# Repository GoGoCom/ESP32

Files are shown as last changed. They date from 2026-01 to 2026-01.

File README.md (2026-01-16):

# ESP32

## Introduction

I created a heater temperature control system using Blynk and an ESP32. The ESP32 is a powerful device with WiFi and Bluetooth capabilities. By combining these two, I created an IoT system that allows remote heaters to be turned on and off at specific temperatures and time periods.
This sketch is implemented provisioning using BLE as the mode of transport for provisioning-related communication between the device (to be provisioned) and the client (owner of the device).

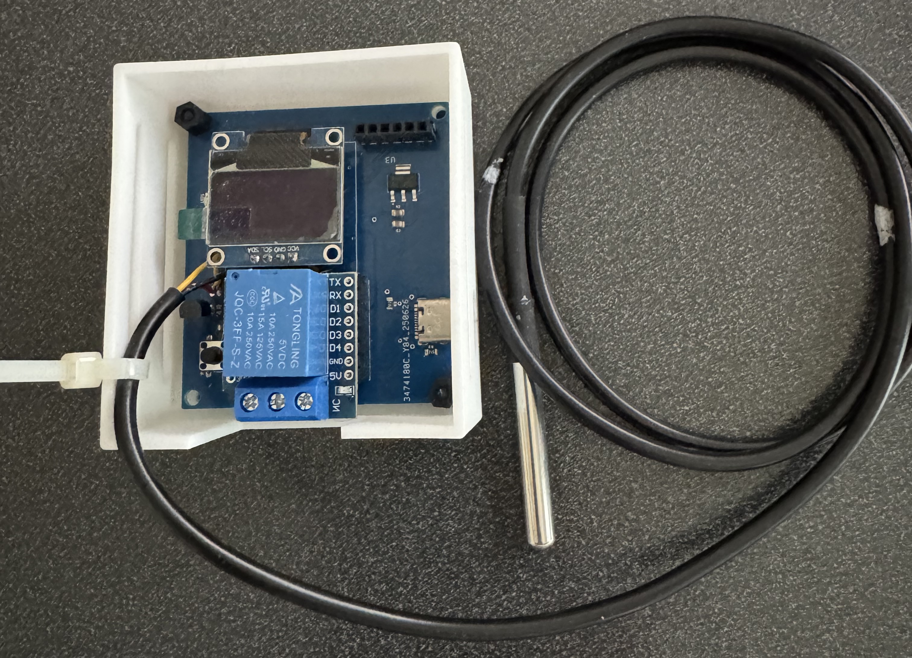
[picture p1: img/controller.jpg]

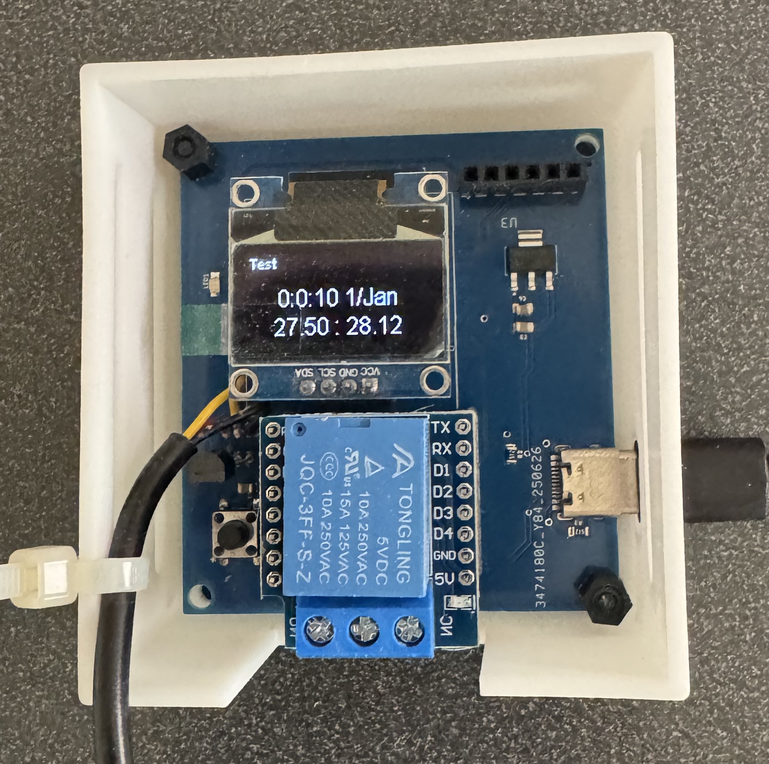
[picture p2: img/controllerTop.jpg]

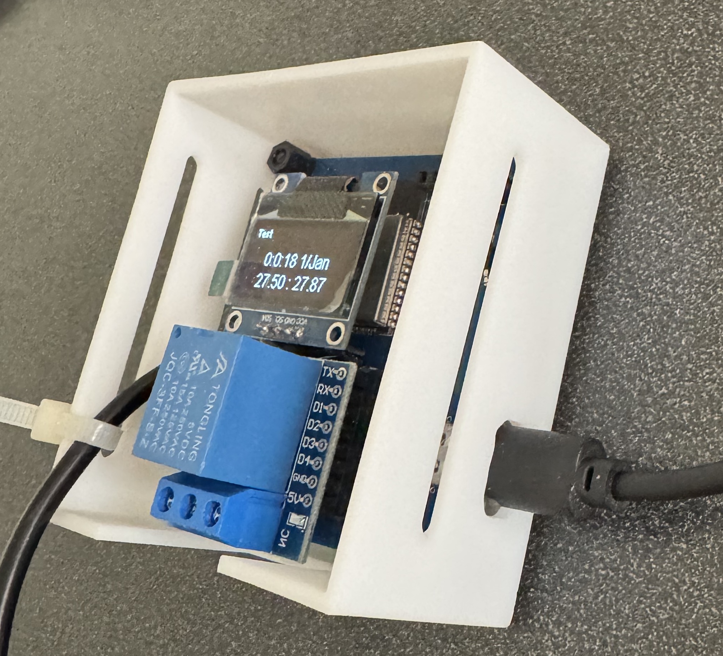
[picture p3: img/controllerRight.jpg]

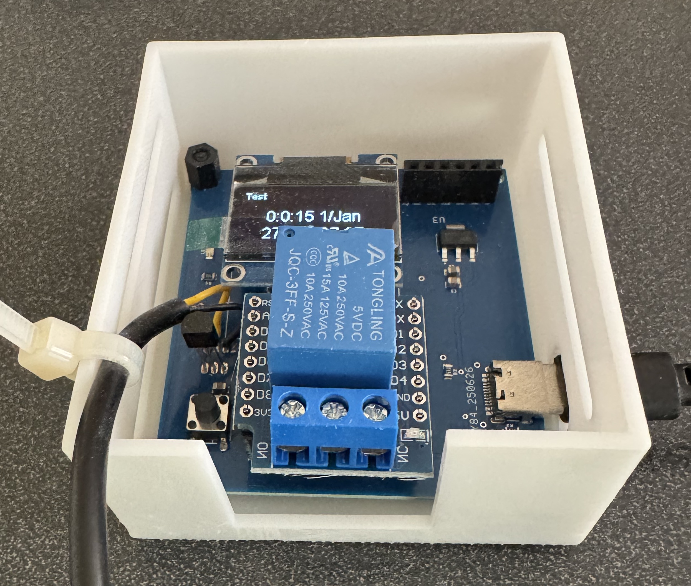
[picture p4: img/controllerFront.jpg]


## Provisioning Tools

### Provisioning using BLE
```

Provisioning started
Give Credentials of your access point using  of "Android app" or "apple asp" ESP BLE Prov.

Received Wi-Fi credentials
    SSID: your own ssid
    Password: your own password

Connected IP address: 192.168.43.120
Provisioning Successful
Provisioning Ends
```

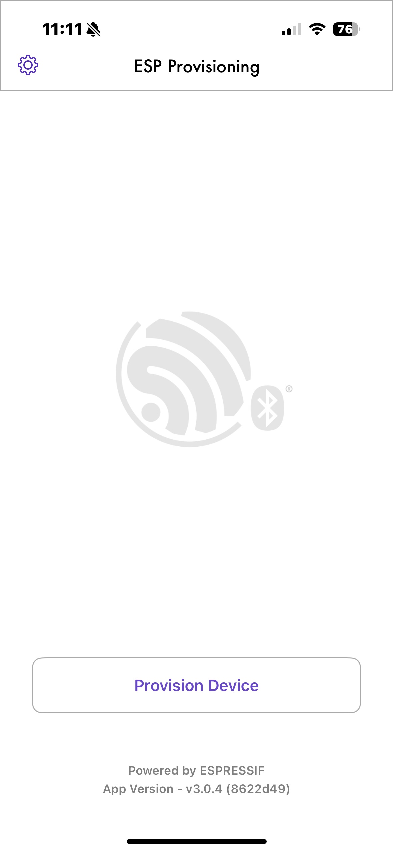
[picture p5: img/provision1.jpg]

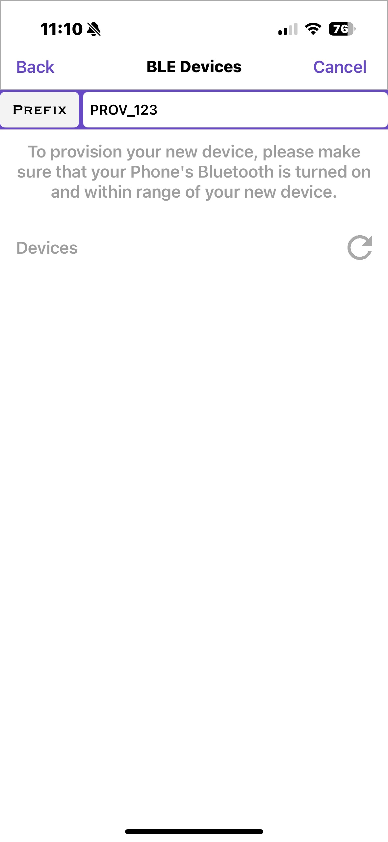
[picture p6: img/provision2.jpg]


## Blynk Tools

[Blynk](https://www.blynk.io/) is an excellent platform for solving IoT problems.It is the most powerful tool when you want to control something on the Internet, whether it is on mobile or PC.
By defining the required streams in the Blynk.Console and connecting them to components, you can exchange data over the network.
You must first sign up on https://blynk.cloud/dashboard/login  before you can use it.

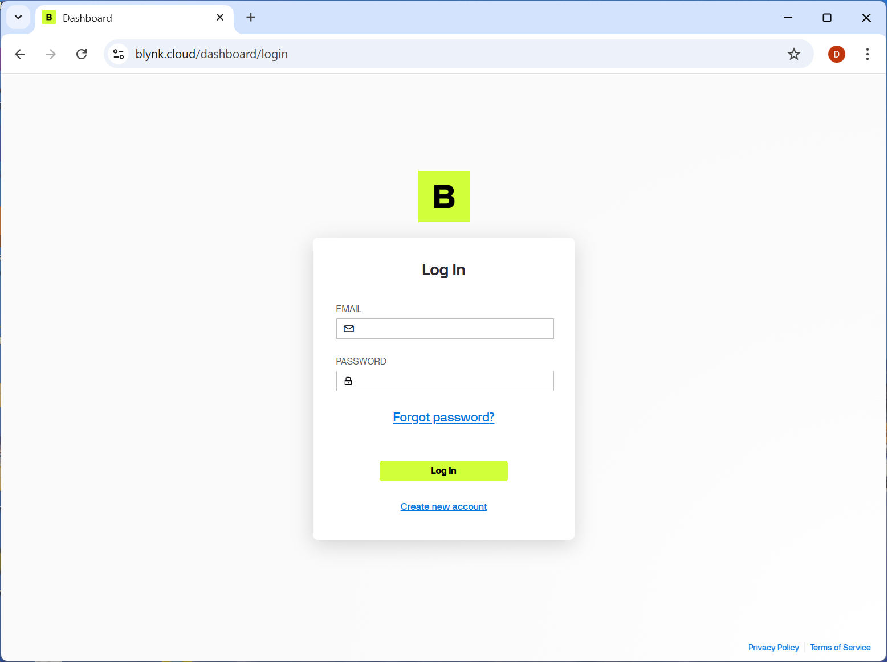
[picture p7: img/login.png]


After defining the device and setting up the development template through the Blynk console, find out the following three values and enter them at the beginning of the source code: BLYNK TEMPLATE ID, BLYNK TEMPLATE_NAME, and BLYNK AUTHTOKEN.

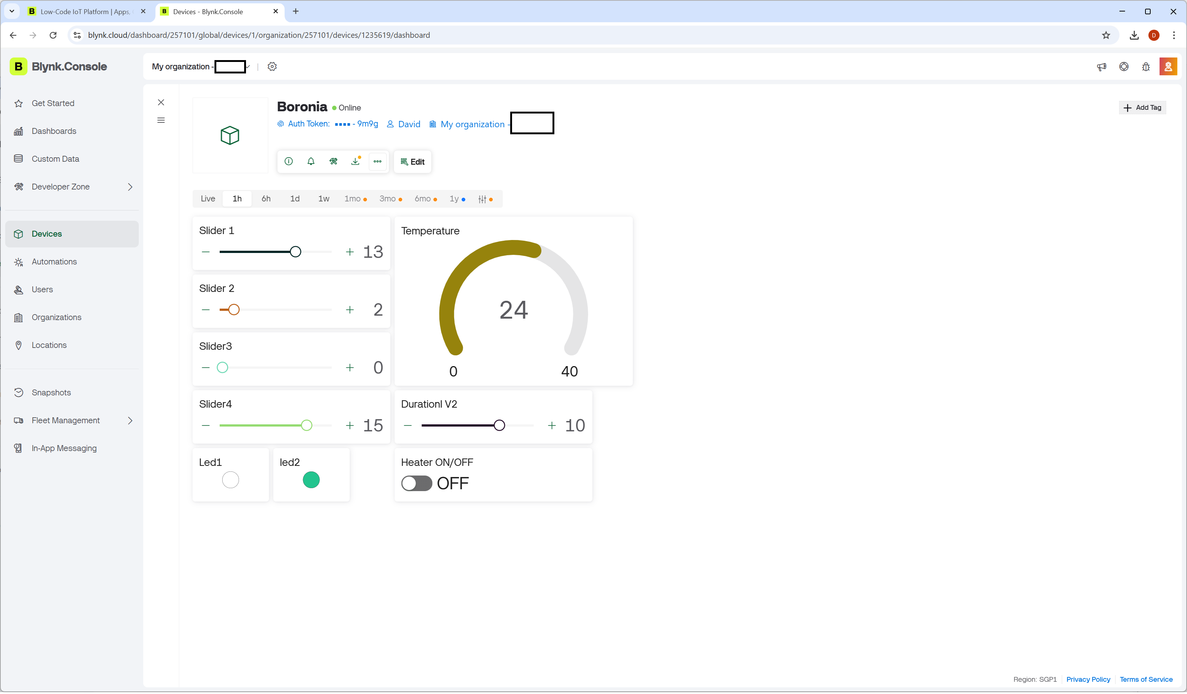
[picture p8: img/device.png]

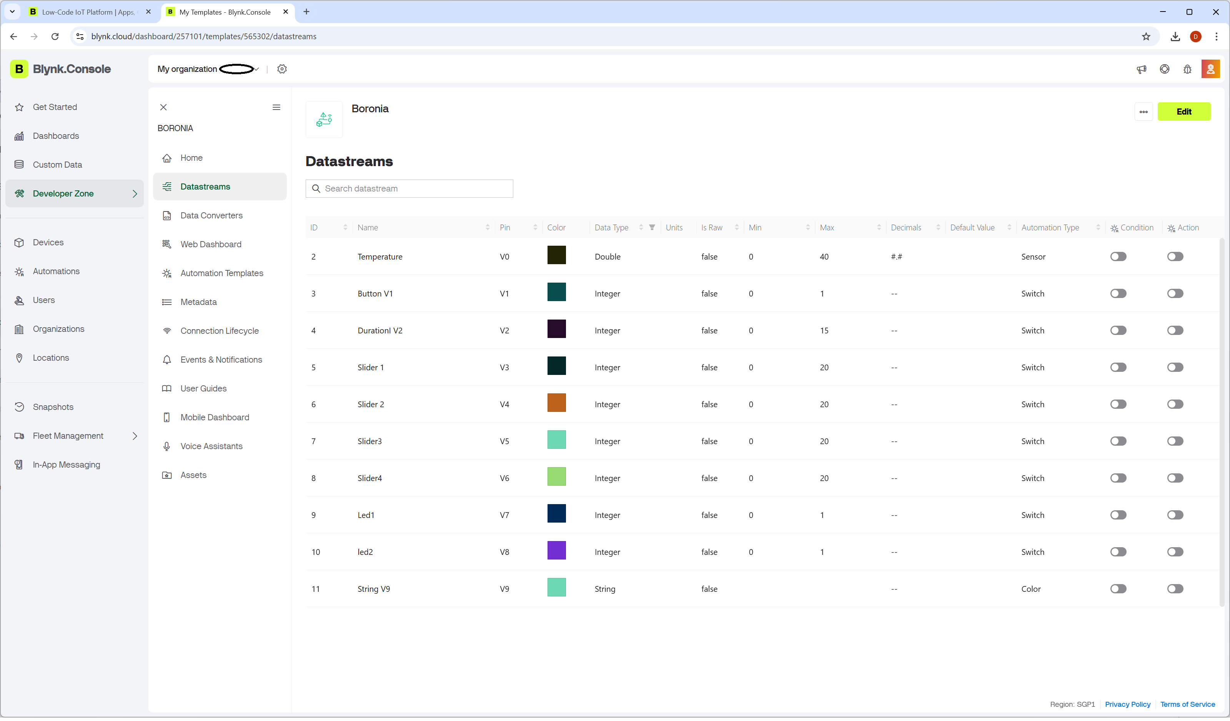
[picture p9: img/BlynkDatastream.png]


| define |
|-|
|#define BLYNK_TEMPLATE_ID  "XMgt6fqp4aXvb" |
|#define BLYNK_TEMPLATE_NAME  "TempControl" |
|#define BLYNK_AUTH_TOKEN  "0f0ffASdldldleefeeXXiCNCvQT3Ff3H" |

### Blynk App / Display

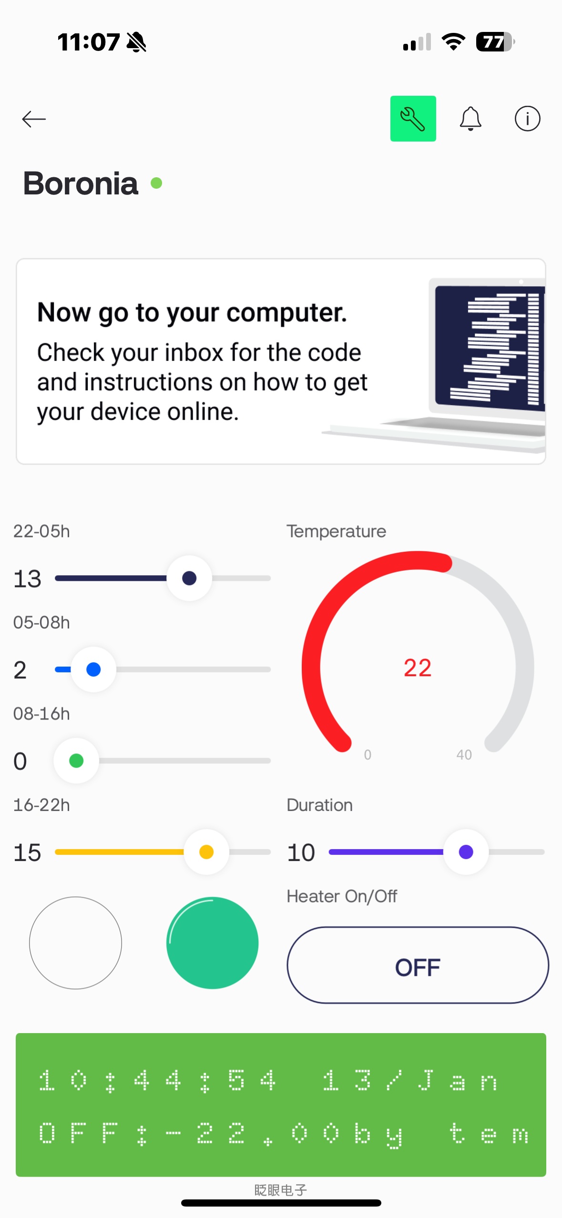
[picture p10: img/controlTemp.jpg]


## Library
| Library | version | description |
|-|-|-|
| Blynk | 1.3.2 | IoT |
| ESP8266 and ESP32 OLED driver foe SSSD1306 | 4.6.2 | display |
| DallasTemperature | 4.0.5 | temperature sensor  |
| Onewire | 2.3.8 | One wire commucarion  |
| Time | 1.6.1 | date and time  |
| OneButton | 2.6.1 | button switch  |

## Tool
| Tool | version | description |
|-|-|-|
| Autodesk Eagle | 9.6.2 | hardware |
| Autodesk Fusion | | case desin for 3D printing |
| Arduino IDE | 2.3.7 | software |

## Acknowledgments

I would like to thank to every one for their contributions.

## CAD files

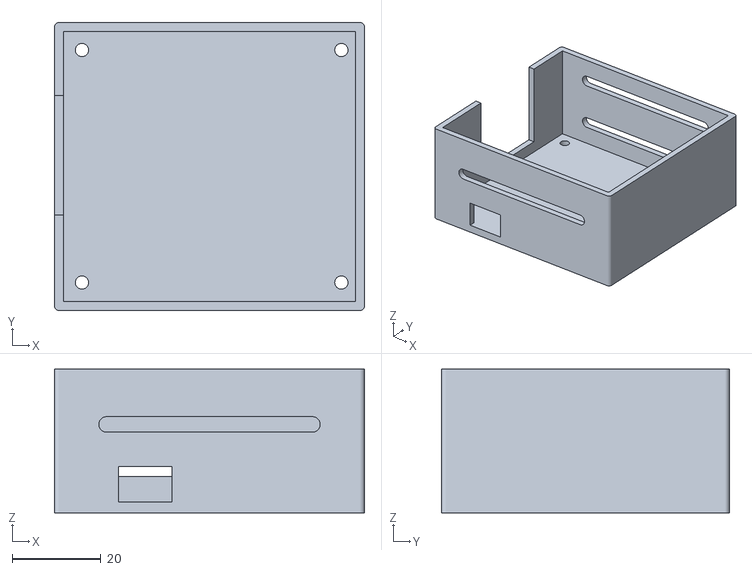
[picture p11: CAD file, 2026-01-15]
case/tempbox v4.stl
70.0 x 65.0 x 32.5

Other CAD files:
case/tempbox.f3d

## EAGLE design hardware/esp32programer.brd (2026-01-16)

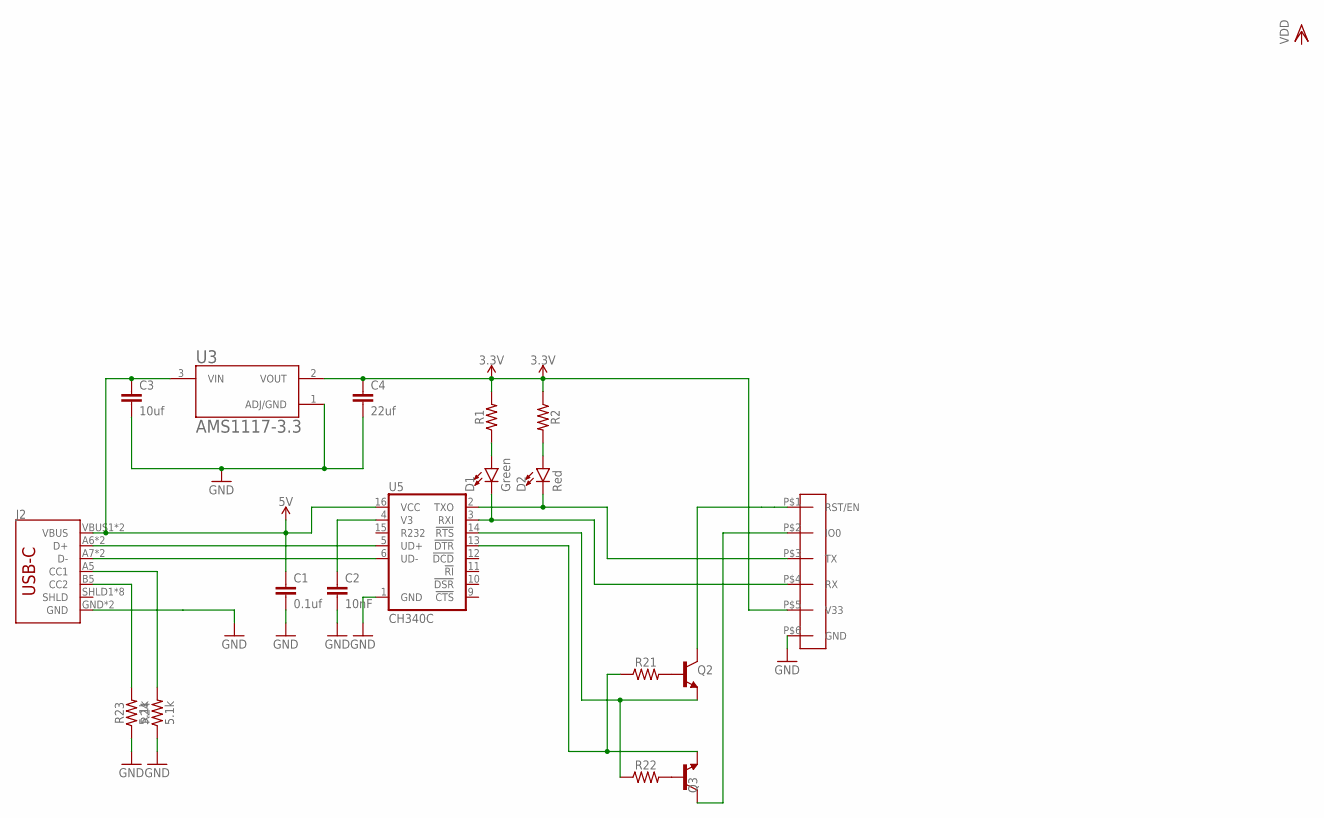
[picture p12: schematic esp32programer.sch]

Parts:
C1: 0.1uf; 0805
C2: 10nF; 0805
C3: 10uf; 0805
C4: 22uf; 0805
D1: Green; LED-0805
D2: Red; LED-0805
J2: USB_C16PIN; USB-C-16P
Q2, Q3: TRANSISTOR_BJT_NPN-SOT-23-BEC; SOT-23
R1, R2, R21, R22: 0805
R23, R24: 5.1k; 0805
U3: AMS1117-3.3; SOT229P700X180-4N
U5: CH340C; SO016
U$6: USBCOUT; 6PINS

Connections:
3.3V: C4.1, R1.2, R2.1, U3.2 (VOUT), U$6.P$5 (V33)
5V: C1.1, C3.1, J2.VBUS1 (VBUS), J2.VBUS2 (VBUS), U3.3 (VIN), U5.16 (VCC)
!DTR: Q3.2 (E), R21.1, U5.13 (!DTR)
CC2: J2.B5 (CC2), R23.2
D+: J2.A6 (D+), J2.B6 (D+), U5.5 (UD+)
D-: J2.A7 (D-), J2.B7 (D-), U5.6 (UD-)
GND: C1.2, C2.2, C3.2, C4.2, J2.GND, J2.GND2 (GND), R23.1, R24.1, U3.1 (ADJ/GND), U5.1 (GND), U$6.P$6 (GND)
unnamed: D1.C, U5.3 (RXI), U$6.P$4 (RX)
unnamed: C2.1, U5.4 (V3)
unnamed: D1.A, R1.1
unnamed: D2.A, R2.2
unnamed: Q2.3 (C), U$6.P$1 (RST/EN)
unnamed: Q3.3 (C), U$6.P$2 (IO0)
unnamed: Q2.2 (E), R22.1, U5.14 (!RTS)
unnamed: Q2.1 (B), R21.2
unnamed: Q3.1 (B), R22.2
unnamed: J2.A5 (CC1), R24.2
RXI: D2.C, U5.2 (TXO), U$6.P$3 (TX)

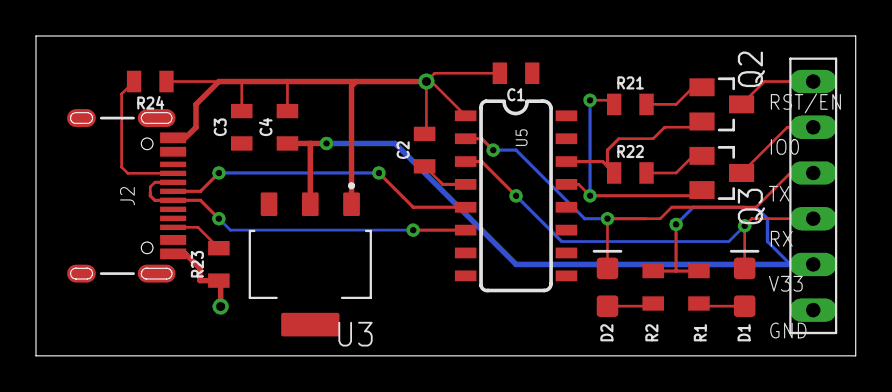
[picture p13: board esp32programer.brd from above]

Board: 2 copper layers, 45.5 x 17.8 mm, 18 parts (0 on the bottom side), 18 nets.

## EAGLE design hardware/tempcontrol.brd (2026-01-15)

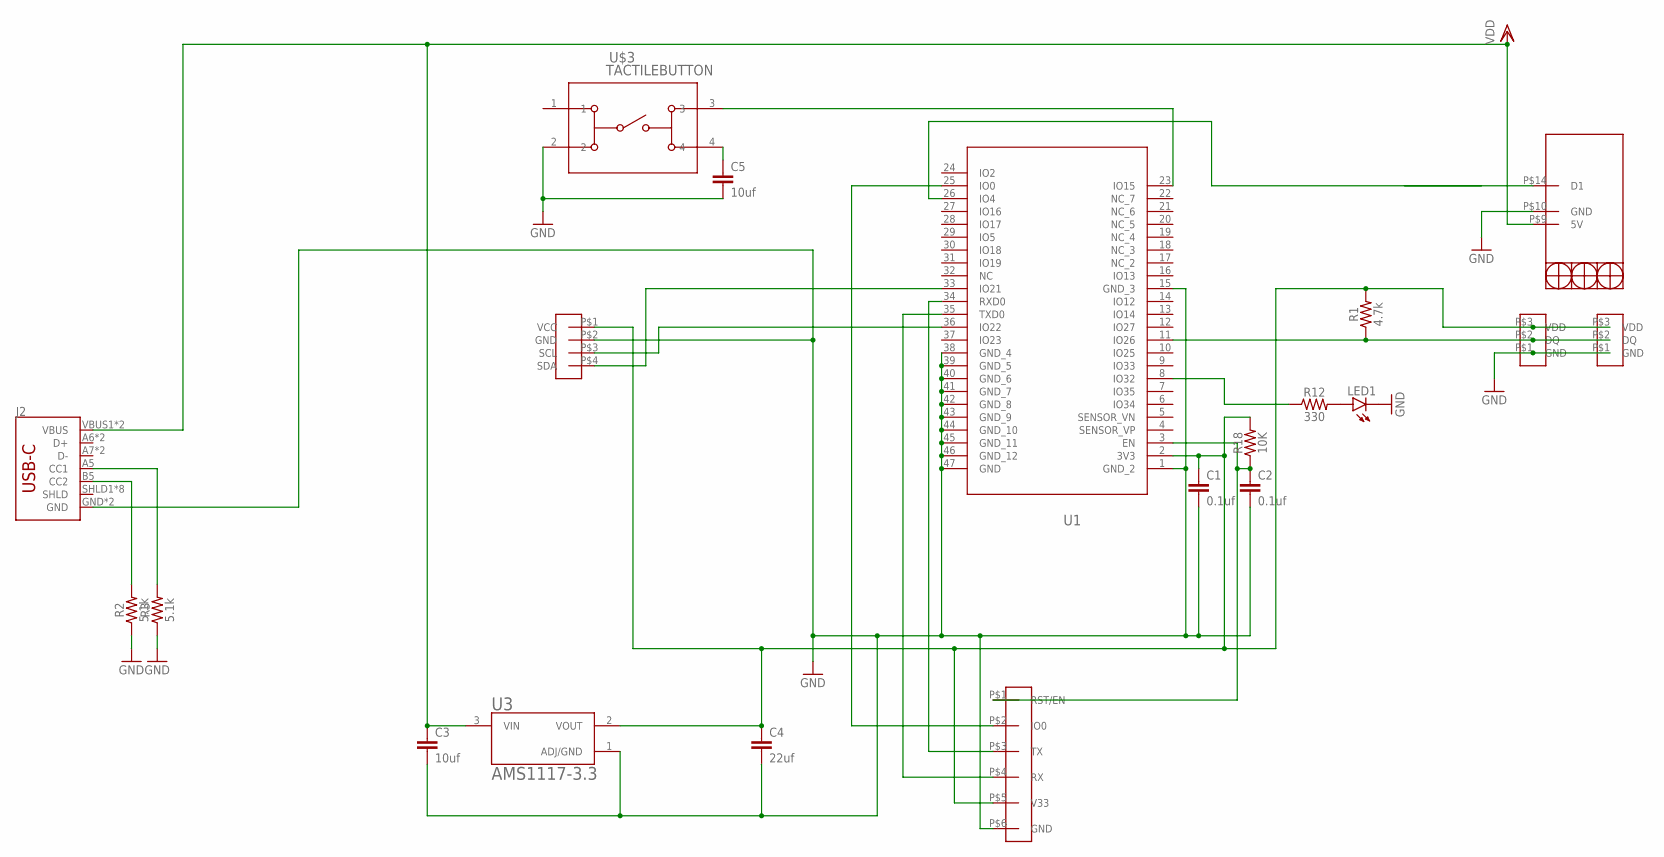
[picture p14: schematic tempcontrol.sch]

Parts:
C1, C2: 0.1uf; 0805
C3, C5: 10uf; 0805
C4: 22uf; 0805
J2: USB_C16PIN; USB-C-16P
LED1: LEDSML0805; SML0805
R1: 4.7k; 0805
R2, R3: 5.1k; 0805
R12: 330; 0805
R18: 10K; 0805
U1: ESP32-WROOM-32E_(4MB)ESP32�WROOM�32E_EXP; ESP32�WROOM�32E_EXP
U3: AMS1117-3.3; SOT229P700X180-4N
U$1: RELAYMINI; 16PINSWIDE
U$2, U$4: DS18B20TR; 3PINS
U$3: TACTILEBUTTON; TACTILEPINS
U$5: USBCOUT; 6PINS
U$18: OLEDVCC; OLEPINS

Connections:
3V3: C1.1, C4.1, R1.2, R18.2, U1.2 (3V3), U3.2 (VOUT), U$2.P$3 (VDD), U$4.P$3 (VDD), U$5.P$5 (V33), U$18.P$1 (VCC)
CC2: J2.B5 (CC2), R2.2
GND: C1.2, C2.2, C3.2, C4.2, C5.2, J2.GND, J2.GND2 (GND), LED1.C, R2.1, R3.1, U1.1 (GND_2), U1.15 (GND_3), U1.38 (GND_4), U1.39 (GND_5), U1.40 (GND_6), U1.41 (GND_7), U1.42 (GND_8), U1.43 (GND_9), U1.44 (GND_10), U1.45 (GND_11), U1.46 (GND_12), U1.47 (GND), U3.1 (ADJ/GND), U$1.P$10 (GND), U$2.P$1 (GND), U$3.2, U$4.P$1 (GND), U$5.P$6 (GND), U$18.P$2 (GND)
unnamed: U1.26 (IO4), U$1.P$14 (D1)
unnamed: C5.1, U$3.4
unnamed: J2.A5 (CC1), R3.2
unnamed: U1.23 (IO15), U$3.3
unnamed: R1.1, U1.11 (IO26), U$2.P$2 (DQ), U$4.P$2 (DQ)
unnamed: LED1.A, R12.2
unnamed: C2.1, R18.1, U1.3 (EN), U$5.P$1 (RST/EN)
unnamed: U1.25 (IO0), U$5.P$2 (IO0)
unnamed: U1.33 (IO21), U$18.P$4 (SDA)
unnamed: U1.35 (TXD0), U$5.P$4 (RX)
unnamed: U1.36 (IO22), U$18.P$3 (SCL)
unnamed: U1.34 (RXD0), U$5.P$3 (TX)
unnamed: R12.1, U1.8 (IO32)
VDD: C3.1, J2.VBUS1 (VBUS), J2.VBUS2 (VBUS), U3.3 (VIN), U$1.P$9 (5V)

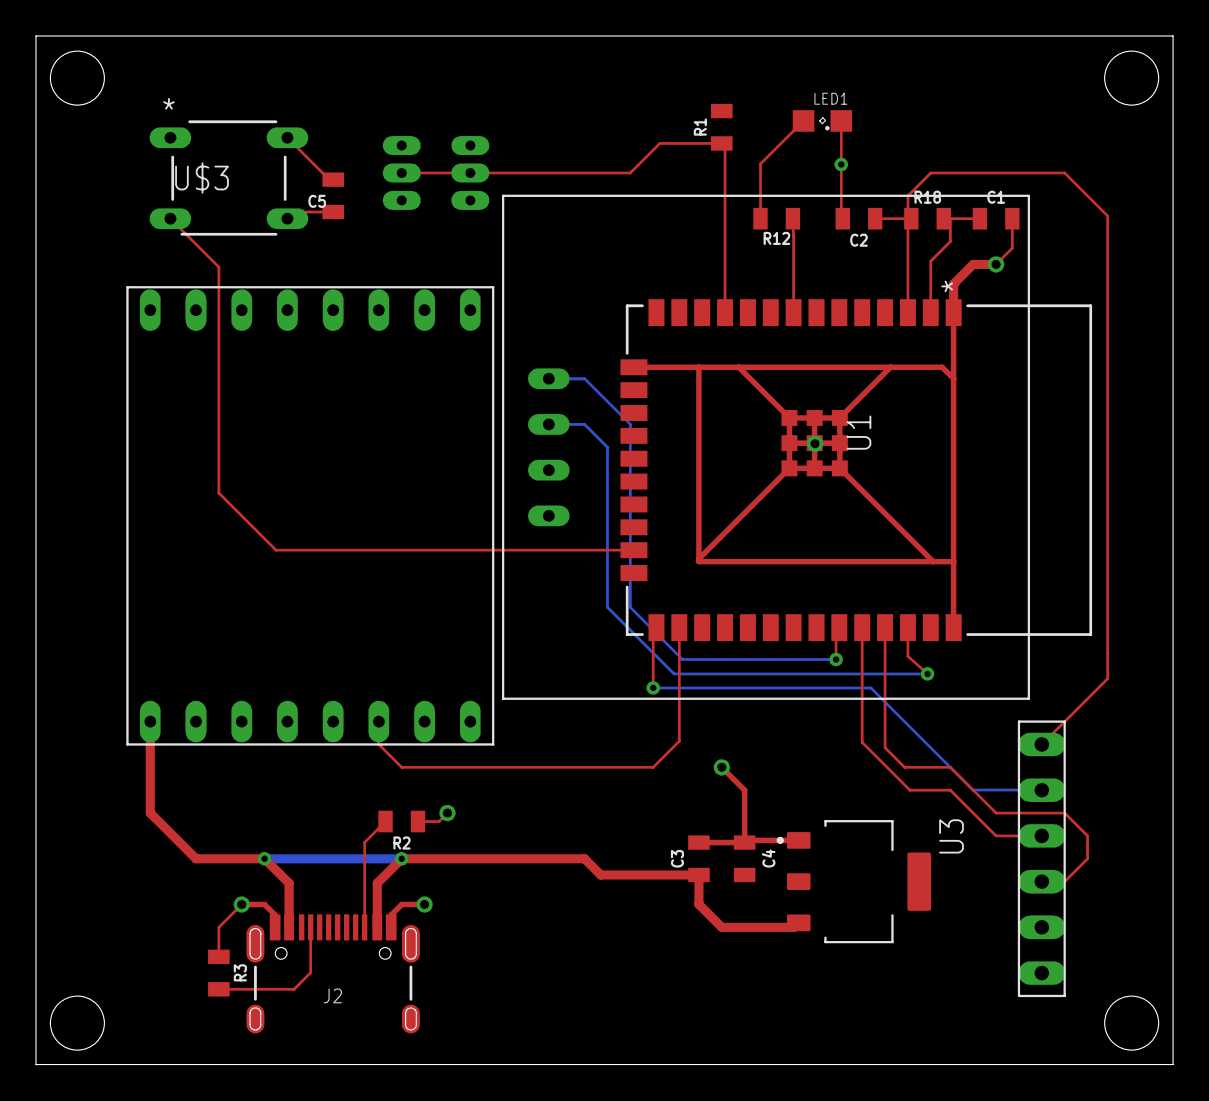
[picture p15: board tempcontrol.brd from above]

Board: 2 copper layers, 63.2 x 57.1 mm, 20 parts (0 on the bottom side), 17 nets.

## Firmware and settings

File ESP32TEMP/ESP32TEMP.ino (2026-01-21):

/*

Please read README.md file in this folder, or on the web:
https://github.com/espressif/arduino-esp32/tree/master/libraries/WiFiProv/examples/WiFiProv

Note: This sketch takes up a lot of space for the app and may not be able to flash with default setting on some chips.
  If you see Error like this: "Sketch too big"
  In Arduino IDE go to: Tools > Partition scheme > chose anything that has more than 1.4MB APP
   - for example "No OTA (2MB APP/2MB SPIFFS)"
*/
/* Comment this out to disable prints and save space */
#define BLYNK_PRINT Serial
/* Fill in information from Blynk Device Info here */

#define BLYNK_TEMPLATE_ID   "TMPLibxxxxxx"   // your template 
#define BLYNK_TEMPLATE_NAME "YYYYYY"
#define BLYNK_AUTH_TOKEN    "skljdfwiiehfiehfwefhjkwe" // your token

#include "sdkconfig.h"
#if CONFIG_ESP_WIFI_REMOTE_ENABLED
#error "WiFiProv is only supported in SoCs with native Wi-Fi support"
#endif

#include <WiFiProv.h>
#include <WiFi.h>
#include <WiFiClient.h>
#include <BlynkSimpleEsp32.h>

#include <EEPROM.h>
#include <math.h>
#include <OneWire.h>
#include <DallasTemperature.h>
#include <TimeLib.h>
#include <WidgetRTC.h>
#include <OneButton.h>

#include <Wire.h>  // Only needed for Arduino 1.6.5 and earlier
#include "SSD1306Wire.h" // legacy include: `#include "SSD1306.h"`


#define OLED

// Data wire is plugged into port 2 on the Arduino
#define ONE_WIRE_BUS 26// 25

#define  RELAY_ON   1 //LOW
#define  RELAY_OFF  0 //HIGH

#define  LED_ON   1 //LOW
#define  LED_OFF  0 //HIGH

#define PIN_INPUT 15

#define BLYNK_RED       "#D3435C"

#define BLYNK_GREEN     "#23C48E"

#define BLYNK_DARK_BLUE "#5F7CD8"
#define BLYNK_BLUE      "#04C0F8"
#define BLYNK_WHITE     "#FFFFFF"
#define BLYNK_YELLOW    "#ED9D00"

#define TEMPERATURE_PRECISION 11 //9

const int relay_pin = 4; //16;   // gpio4
const int led_pin   = 32; //23;   // gpio12
const int btn_pin   = 15; //23;   

SSD1306Wire display(0x3c, SDA, SCL);   

// Setup a oneWire instance to communicate with any OneWire devices (not just Maxim/Dallas temperature ICs)
OneWire oneWire(ONE_WIRE_BUS);
// Pass our oneWire reference to Dallas Temperature. 
DallasTemperature sensors(&oneWire);

// arrays to hold device addresses
DeviceAddress insideThermometer, outsideThermometer;

BlynkTimer timer;
WidgetLCD lcd(V9);
WidgetRTC rtc;
WidgetLED led1(V7), led2(V8);

OneButton button(PIN_INPUT, true);

String strShortMessage;

int    ScanResult, ConnectResult;

int  s_led_now, s_display_sw;

float  g_temperature;  
float  TempC = 0.0, TempF = 0.0, TempCI = 0.0, TempCO = 0.0; 


 
struct WIFI {
  char  SID[51];
  char  PWD[51];
  char  AUT[51];
  char  REV[21];
};

struct NOW {
  boolean  g_checked;
  uint8_t  g_duration;
};

struct TEMP {
  float    g_temperature;
  uint8_t  g_start_hour;
  uint8_t  g_end_hour;
};

struct {
  struct WIFI W;
  struct NOW  N;
  struct TEMP T[4];
} Info;

// #define USE_SOFT_AP // Uncomment if you want to enforce using the Soft AP method instead of BLE
const char *pop = "abcd1234";           // Proof of possession - otherwise called a PIN - string provided by the device, entered by the user in the phone app
const char *service_name = "PROV_123";  // Name of your device (the Espressif apps expects by default device name starting with "Prov_")
const char *service_key = NULL;         // Password used for SofAP method (NULL = no password needed)
bool reset_provisioned = true;          // When true the library will automatically delete previously provisioned data.

// WARNING: SysProvEvent is called from a separate FreeRTOS task (thread)!
void SysProvEvent(arduino_event_t *sys_event) {
  switch (sys_event->event_id) {
    case ARDUINO_EVENT_WIFI_STA_GOT_IP:
      Serial.print("\nConnected IP address : ");
      Serial.println(IPAddress(sys_event->event_info.got_ip.ip_info.ip.addr));
      break;
    case ARDUINO_EVENT_WIFI_STA_DISCONNECTED: Serial.println("\nDisconnected. Connecting to the AP again... "); break;
    case ARDUINO_EVENT_PROV_START:            Serial.println("\nProvisioning started\nGive Credentials of your access point using smartphone app"); break;
    case ARDUINO_EVENT_PROV_CRED_RECV:
    {
      Serial.println("\nReceived Wi-Fi credentials");
      Serial.print("\tSSID : ");
      Serial.println((const char *)sys_event->event_info.prov_cred_recv.ssid);
      Serial.print("\tPassword : ");
      Serial.println((char const *)sys_event->event_info.prov_cred_recv.password);
      strcpy(Info.W.SID, (char const *)sys_event->event_info.prov_cred_recv.ssid);
      strcpy(Info.W.PWD, (char const *)sys_event->event_info.prov_cred_recv.password);
      WriteAllToEEPROM();
      DisplayMessage("Temp Control", "Provision", "credentials");
      break;
    }
    case ARDUINO_EVENT_PROV_CRED_FAIL:
    {
      Serial.println("\nProvisioning failed!\nPlease reset to factory and retry provisioning\n");
      if (sys_event->event_info.prov_fail_reason == NETWORK_PROV_WIFI_STA_AUTH_ERROR) {
        Serial.println("\nWi-Fi AP password incorrect");
      } else {
        Serial.println("\nWi-Fi AP not found....Add API \" nvs_flash_erase() \" before beginProvision()");
      }
      break;
    }
    case ARDUINO_EVENT_PROV_CRED_SUCCESS: {
      DisplayMessage("Temp Control", "Provision", "success");
      Serial.println("\nProvisioning Successful");
      break;
    }
    case ARDUINO_EVENT_PROV_END:          Serial.println("\nProvisioning Ends"); ESP.restart();  break;
    default:                              break;
  }
}


// BLYNK Subroutine
BLYNK_CONNECTED() {
    // Request Blynk server to re-send latest values for all pins
 
    Blynk.syncAll();
    Serial.println("Sync!");
/*
    Blynk.virtualWrite(V1, Info.N.g_checked); 
    Blynk.virtualWrite(V2, Info.N.g_duration );   
    Blynk.virtualWrite(V3, Info.T[0].g_temperature );   
    Blynk.virtualWrite(V4, Info.T[1].g_temperature );   
    Blynk.virtualWrite(V5, Info.T[2].g_temperature );   
    Blynk.virtualWrite(V6, Info.T[3].g_temperature );   
*/   
    led1.off();
    led2.off();

}

BLYNK_WRITE(V1) // Button
{
  int pinValue = param.asInt();

  if( pinValue == 1 ) {
       led2.off(); // time mode 
       HeaterOn(1, "by button");  
  } else {
       HeaterOff(0, "by button");
  }
  Info.N.g_checked = pinValue;

}

BLYNK_WRITE(V2) // Duration Slider
{
  Info.N.g_duration = param.asInt();
  WriteToEEPROM(long(&Info.N.g_duration), sizeof(Info.N.g_duration));  
}

BLYNK_WRITE(V3) // 22-04h Slider 
{
  Info.T[0].g_temperature = param.asFloat();
  WriteToEEPROM(long(&Info.T[0].g_temperature), sizeof(Info.T[0].g_temperature));  
}

BLYNK_WRITE(V4) // 04-08h Slider
{
  Info.T[1].g_temperature = param.asFloat();
  WriteToEEPROM(long(&Info.T[1].g_temperature), sizeof(Info.T[1].g_temperature)); 
}

BLYNK_WRITE(V5) // 08-16h Slider
{
  Info.T[2].g_temperature = param.asFloat();
  WriteToEEPROM(long(&Info.T[2].g_temperature), sizeof(Info.T[2].g_temperature));  
}

BLYNK_WRITE(V6) // 16-22h Slider
{
  Info.T[3].g_temperature = param.asFloat(); 
  WriteToEEPROM(long(&Info.T[3].g_temperature), sizeof(Info.T[3].g_temperature));  
}

// function to print a device address
void printAddress(DeviceAddress deviceAddress)
{
  for (uint8_t i = 0; i < 8; i++)
  {
    // zero pad the address if necessary
    if (deviceAddress[i] < 16) Serial.print("0");
    Serial.print(deviceAddress[i], HEX);
  }
}

// function to print the temperature for a device
float printTemperature(DeviceAddress deviceAddress)
{
  float tempC = sensors.getTempC(deviceAddress);
  if (tempC == DEVICE_DISCONNECTED_C)
  {
    Serial.println("Error: Could not read temperature data");
    return 0;
  }
  Serial.print("Temp C: ");
  Serial.println(tempC);
//  Serial.print(" Temp F: ");
//  Serial.print(DallasTemperature::toFahrenheit(tempC));
  return tempC;
}

// function to print a device's resolution
void printResolution(DeviceAddress deviceAddress)
{
  Serial.print("Resolution: ");
  Serial.print(sensors.getResolution(deviceAddress));
  Serial.println();
}

// main function to print information about a device
float printData(DeviceAddress deviceAddress)
{
  Serial.print("Device Address: ");
  printAddress(deviceAddress);
  Serial.print(" ");
  return printTemperature(deviceAddress);
}

void SensorSetup(void) // Temperature sensor set up
{
  // start serial port
  Serial.println("Dallas Temperature IC Control Set up");

  // Start up the library
  sensors.begin();

  // locate devices on the bus
  Serial.print("Locating devices...");
  Serial.print("Found ");
  Serial.print(sensors.getDeviceCount(), DEC);
  Serial.println(" devices.");

  // report parasite power requirements
  Serial.print("Parasite power is: ");
  if (sensors.isParasitePowerMode()) Serial.println("ON");
  else Serial.println("OFF");

  // Search for devices on the bus and assign based on an index. Ideally,
  // you would do this to initially discover addresses on the bus and then
  // use those addresses and manually assign them (see above) once you know
  // the devices on your bus (and assuming they don't change).
  //
  // method 1: by index
  if (!sensors.getAddress(insideThermometer, 0)) Serial.println("Unable to find address for Device 0");
  if (!sensors.getAddress(outsideThermometer, 1)) Serial.println("Unable to find address for Device 1");

  // method 2: search()
  // search() looks for the next device. Returns 1 if a new address has been
  // returned. A zero might mean that the bus is shorted, there are no devices,
  // or you have already retrieved all of them. It might be a good idea to
  // check the CRC to make sure you didn't get garbage. The order is
  // deterministic. You will always get the same devices in the same order
  //
  // Must be called before search()
  //oneWire.reset_search();
  // assigns the first address found to insideThermometer
  //if (!oneWire.search(insideThermometer)) Serial.println("Unable to find address for insideThermometer");
  // assigns the seconds address found to outsideThermometer
  //if (!oneWire.search(outsideThermometer)) Serial.println("Unable to find address for outsideThermometer");

  // show the addresses we found on the bus
  Serial.print("Device 0 Address: ");
  printAddress(insideThermometer);
  Serial.println();

  Serial.print("Device 1 Address: ");
  printAddress(outsideThermometer);
  Serial.println();

  // set the resolution to 9 bit per device
  sensors.setResolution(insideThermometer, TEMPERATURE_PRECISION);
  sensors.setResolution(outsideThermometer, TEMPERATURE_PRECISION);

  Serial.print("Device 0 Resolution: ");
  Serial.print(sensors.getResolution(insideThermometer), DEC);
  Serial.println();

  Serial.print("Device 1 Resolution: ");
  Serial.print(sensors.getResolution(outsideThermometer), DEC);
  Serial.println();
}

//
void Initialize()
{ 

  s_display_sw = 1;
  g_temperature = 0.0f;
  s_led_now   = 0;
  strShortMessage  = "";
  ScanResult    = 0;
  ConnectResult = -1;

  pinMode(relay_pin, OUTPUT);
  pinMode(32, OUTPUT);
  
  digitalWrite(32,   1);    
  digitalWrite(relay_pin, RELAY_OFF); 

  Serial.begin(115200); 

  SensorSetup();
  
  EEPROM.begin( sizeof(Info) );

  ReadAllFromEEPROM();

  Info.N.g_checked = false;

  Info.T[0].g_start_hour = 22;
  Info.T[0].g_end_hour = 5;
  Info.T[1].g_start_hour = 5;
  Info.T[1].g_end_hour = 8;
  Info.T[2].g_start_hour = 8;
  Info.T[2].g_end_hour = 16;
  Info.T[3].g_start_hour = 16;
  Info.T[3].g_end_hour = 22;      

  Serial.println("MSG\tSystem Initialize !");
  delay(2000);

  Serial.println(Info.N.g_duration);
  Serial.println(Info.T[0].g_temperature);
  Serial.println(Info.T[1].g_temperature);
  Serial.println(Info.T[2].g_temperature);
  Serial.println(Info.T[3].g_temperature);
  // link functions to be called on events.
  //button.attachLongPressStart(LongPressStart, &button);
  //button.attachDuringLongPress(DuringLongPress, &button);
  //button.attachLongPressStop(LongPressStop, &button);

    button.attachClick(ClickPress, &button);
  //  button.attachDoubleClick(DoublePress, &button);


 // button.setLongPressIntervalMs(1000);

 test();

}

void test() {

   String strTime, strTemp;
 
   while(1) {
    getTemperature();

   strTime = String(hour()) + ":" + String(minute()) + ":" + String(second()) + " " + String(day()) + "/" + monthShortStr(month());
   strTemp = String(TempCI) + " : " + String(TempCO);
// String(TempC); // String(TempCI) + " : " + String(TempCO);

    display.clear();
    display.setTextAlignment(TEXT_ALIGN_LEFT);
    display.setFont(ArialMT_Plain_10);
    display.drawString(0, 0, "Test");
    display.setTextAlignment(TEXT_ALIGN_CENTER);
    display.setFont(ArialMT_Plain_16);
    display.drawString(64, 22, strTime);
    display.drawString(64, 42, strTemp);
    display.display();

    digitalWrite(relay_pin, RELAY_ON);
    delay(1000);
    digitalWrite(relay_pin, RELAY_OFF);
    delay(1000);
    
   }

}
void DisplayMessage(const char *msg1, const char *msg2, const char *msg3)
{
 if( s_display_sw == 1 ) {
    display.clear();
    display.setTextAlignment(TEXT_ALIGN_LEFT);
    display.setFont(ArialMT_Plain_10);
    display.drawString(0, 0, msg1);
    display.setTextAlignment(TEXT_ALIGN_CENTER);
    display.setFont(ArialMT_Plain_16);
    display.drawString(64, 22, msg2);
    display.drawString(64, 42, msg3);
    display.display();
  } else {
    display.clear();
    display.display();
  }

 lcd.clear();
 lcd.print(0, 0, msg1 );   
 lcd.print(0, 1, msg3 );  
}

void DisplayAction(const char *msg3)
{
  /*
  #ifdef OLED
    display.setTextAlignment(TEXT_ALIGN_CENTER);
    display.setFont(ArialMT_Plain_16);
    display.drawString(64, 42, msg3);
    display.display();
  #endif
  */

 lcd.print(0, 1, "                " );  
 lcd.print(0, 1, msg3 );  
}

void CheckStatus()
{
  static int gab_minute;
  int    t_hour;

  if( Info.N.g_checked == true ) {       // Now On
     gab_minute ++;           
     if( gab_minute  >  Info.N.g_duration  ) {
        Info.N.g_checked  =  false;
        Blynk.virtualWrite(V1, Info.N.g_checked); // button off automatically 
        HeaterOff(0, "by time");              
        gab_minute = 0; 
     }
     return;
  }    
  if( Info.N.g_checked == false ) {       // Now Off & Start by temp     
     t_hour = hour();    
     for(int i=0; i<4; i++ ) {      
        if( i == 0 ) {
          if(( t_hour >= Info.T[0].g_start_hour ) || ( t_hour < Info.T[0].g_end_hour ) ) {
              led2.setColor(BLYNK_DARK_BLUE); // 22-04h temp mode
              g_temperature = Info.T[i].g_temperature;
              break;
          }          
        } else {  
          if(( Info.T[i].g_start_hour <= t_hour) && ( t_hour < Info.T[i].g_end_hour ) ) {
              switch(i) {
                case 1:
                          led2.setColor(BLYNK_BLUE); // 04-10h temp mode
                          break;
                case 2:
                          led2.setColor(BLYNK_GREEN); // 10-17h temp mode
                          break;
                case 3:
                          led2.setColor(BLYNK_YELLOW); // 17-22h temp mode
                          break;
              }
              g_temperature = Info.T[i].g_temperature;
              break;
          }          
        }
    }
    HeaterByTemperature();            
    led2.on(); // temp mode          
  }
}

void SendStatus()
{
 String strTime, strTemp;
 
  getTemperature();

  Blynk.virtualWrite(V0, TempC);  // Gadge 

// strTime = String(hour()) + ":" + String(minute()) + ":" + String(second()) + " " + dayShortStr(weekday()) + " " + String(day()) + "/" + monthShortStr(month()) + "/" + String(year());
 strTime = String(hour()) + ":" + String(minute()) + ":" + String(second()) + " " + String(day()) + "/" + monthShortStr(month());
 strTemp = String(TempC) + " : " + String(g_temperature);

 DisplayMessage(strTime.c_str(), strTemp.c_str(), strShortMessage.c_str());

}

// Adapted from Adafruit_SSD1306
void drawRect(void) {
  for (int16_t i = 0; i < display.getHeight() / 2; i += 2) {
    display.drawRect(i, i, display.getWidth() - 2 * i, display.getHeight() - 2 * i);
    display.display();
    delay(10);
  }
}

void HeaterOn(int Status, String shortMsg)
{
     led1.on();
     s_led_now  = Status;
     digitalWrite(relay_pin, RELAY_ON);
     
     strShortMessage = " ON:" + shortMsg;
     Serial.println("MSG\t"+strShortMessage );   
     DisplayAction(strShortMessage.c_str());    
}

void HeaterOff(int Status, String shortMsg)
{
     led1.off();
     s_led_now  = Status;
     digitalWrite(relay_pin, RELAY_OFF);
     
     strShortMessage = "OFF:" + shortMsg;
     Serial.println("MSG\t"+strShortMessage );
     DisplayAction(strShortMessage.c_str());           
}

void HeaterByTemperature(void)
{
  String strTemp;
  
  getTemperature();

  Blynk.virtualWrite(V0, TempC);  // Gadge 

  strTemp = String(g_temperature - TempC);
  
     if(  (g_temperature - TempC) > 0.7f  ) {
          HeaterOn(2,  strTemp+"by temp!");
     }    
     if(  TempC >= g_temperature  ) {
          HeaterOff(0, strTemp+"by temp!");
     }
}

void getTemperature(void)
{  

  sensors.requestTemperatures();

  // print the device information
  TempCI = printData(insideThermometer);
  TempCO = printData(outsideThermometer);
  TempC = TempCI; // (tempCI + tempCO) / 2 - 3.0f;

  Serial.print("Temperature : ");
  Serial.println(TempC);

  return;



  sensors.requestTemperatures();

  TempC = sensors.getTempCByIndex(0); // outside 

 // Check if reading was successful
  if(TempC != DEVICE_DISCONNECTED_C) 
  {
    Serial.print("Temperature : ");
    Serial.println(TempC);
  } 
  else
  {
    TempC = -0.0;
    Serial.println("Error: Could not read temperature data");
    DisplayMessage("Temp Control", "Error!", "can't read temp");    
  }

  TempF  = DallasTemperature::toFahrenheit(TempC);

}

void ReadAllFromEEPROM()
{
 int i;
byte value;

  // read the value to the appropriate byte of the EEPROM.
  for( i=0; i<sizeof(Info); i ++) {
    value = EEPROM.read(i);
    *(Info.W.SID + i) =  value;
    //delay(100);
  }
  
}

void WriteAllToEEPROM()
{
   int  i;
  byte value;

  // write the value to the appropriate byte of the EEPROM.
  for( i=0; i<sizeof(Info); i ++) {
    value = *(Info.W.SID + i);
    EEPROM.write(i, value);
    delay(100);
  }  

  EEPROM.commit();
}

void WriteToEEPROM(long taddr, int len)
{
  int addr, i;
  byte value;

  addr = taddr - long( &Info );  
  for( i=0; i<len; i ++) {
    value = *(Info.W.SID + addr + i);    
    EEPROM.write(addr + i, value);
    delay(100);
  }

  EEPROM.commit();
}

void SystemReset()
{
  memset(Info.W.SID, 0, sizeof(Info) );
  WriteAllToEEPROM();
  Serial.println("Reseted!");
}

void Provisioning() {
 // Serial.begin(115200);

    WiFi.begin();  // no SSID/PWD - get it from the Provisioning APP or from NVS (last successful connection)
    WiFi.onEvent(SysProvEvent);

  // BLE Provisioning using the ESP SoftAP Prov works fine for any BLE SoC, including ESP32, ESP32S3 and ESP32C3.
  #if CONFIG_BLUEDROID_ENABLED && !defined(USE_SOFT_AP)
    Serial.println("Begin Provisioning using BLE");
    // Sample uuid that user can pass during provisioning using BLE
    uint8_t uuid[16] = {0xb4, 0xdf, 0x5a, 0x1c, 0x3f, 0x6b, 0xf4, 0xbf, 0xea, 0x4a, 0x82, 0x03, 0x04, 0x90, 0x1a, 0x02};
    WiFiProv.beginProvision(
      NETWORK_PROV_SCHEME_BLE, NETWORK_PROV_SCHEME_HANDLER_FREE_BLE, NETWORK_PROV_SECURITY_1, pop, service_name, service_key, uuid, reset_provisioned
    );
    DisplayMessage("Temp Control", "Provision", "ble qr scan");
    Serial.println("ble qr");
    WiFiProv.printQR(service_name, pop, "ble");
  #else
    Serial.println("Begin Provisioning using Soft AP");
    WiFiProv.beginProvision(NETWORK_PROV_SCHEME_SOFTAP, NETWORK_PROV_SCHEME_HANDLER_NONE, NETWORK_PROV_SECURITY_1, pop, service_name, service_key);
    DisplayMessage("Temp Control", "Provision", "wifi qr scan");
    Serial.println("wifi qr");
    WiFiProv.printQR(service_name, pop, "softap");
  #endif

}
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
void loop(void)
{

  if( ConnectResult == 1 ) {
     Blynk.run();
     timer.run();   
     button.tick();
  } 
  
}

// this function will be called when the button started long pressed.
void LongPressStart(void *oneButton)
{
  Serial.print(((OneButton *)oneButton)->getPressedMs());
  Serial.println("\t - LongPressStart()");
}

// this function will be called when the button is released.
void LongPressStop(void *oneButton)
{
  Serial.print(((OneButton *)oneButton)->getPressedMs());
  Serial.println("\t - LongPressStop()\n");
}

// this function will be called when the button is held down.
void DuringLongPress(void *oneButton)
{
  Serial.print(((OneButton *)oneButton)->getPressedMs());
  Serial.println("\t - DuringLongPress()");
}
// this function will be called when the button is held down.
void ClickPress(void *oneButton)
{
  Serial.print(((OneButton *)oneButton)->getPressedMs());
  Serial.println("\t - ClickPress()");
  if( s_display_sw == 0 ) s_display_sw == 1;
  else s_display_sw == 0;
}
// this function will be called when the button is held down.
void DoublePress(void *oneButton)
{
  Serial.print(((OneButton *)oneButton)->getPressedMs());
  Serial.println("\t - DoublePress()");
}

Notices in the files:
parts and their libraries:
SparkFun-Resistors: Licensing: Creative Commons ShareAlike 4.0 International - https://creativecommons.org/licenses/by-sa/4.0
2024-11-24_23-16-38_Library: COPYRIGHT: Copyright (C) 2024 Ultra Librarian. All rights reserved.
